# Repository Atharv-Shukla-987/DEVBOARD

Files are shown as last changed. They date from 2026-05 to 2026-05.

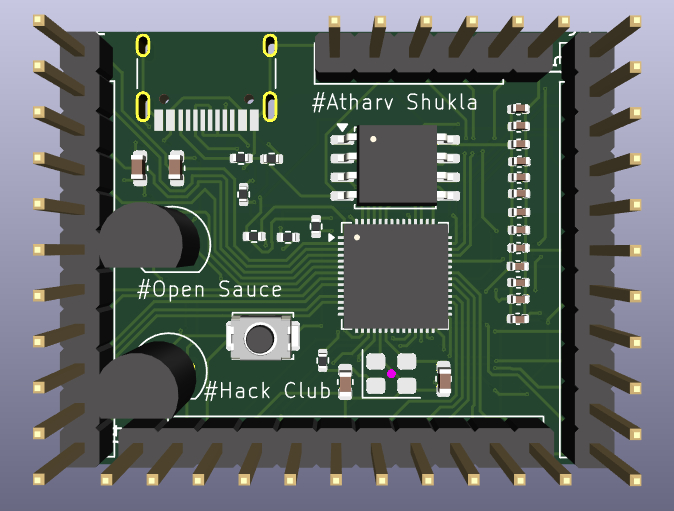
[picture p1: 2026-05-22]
img/Pcb_3d_front.png

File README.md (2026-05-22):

# DEVBOARD
It is devboard made with the help of rp2040 . I try to make it as compact as possible  thus it is a square shaped devboard .It also have many gpio pins. It has following features

##### It has usb C port
##### It has 16MB external QSPI flash
##### It has 1 VBUS , 3v3 and Clock pins 
##### It has 29 gpio pins
##### It has tactile push button for reset

 ## COMPONENTS
#### RP2040
#### MCP1700x-3.3V LDO Regulator (TO-92)
#### W25Q128JVS — 128Mb SPI Flash (SOIC-8)
#### 12 MHz Crystal Oscillator
#### USB-C Receptacle
#### Pin HeaderS
#### Tactile Push Button
#### Capacitors
#### Resistors
 
 ## SCHEMATICS
 I have designed this devboard using kicad. Here are some images

 ### RP2040
RP2040

### USB

Usb

### PINOUT

Pinout

### FLASH STROAGE

Flash Strorage

### CRYSTAL OSCILLATOR

Crystal Oscillator

### DECOUPLING

Decoupling

## FOOTPRINTS
Footprint1

Footprint2

## PCB EDITOR
This is how I traced my devboad.Here its image 

Pcb editor

## 3D VIEW

This how it will look in real life.

### Front

Pcb_3d_front

### Back

Pcb_3d_back

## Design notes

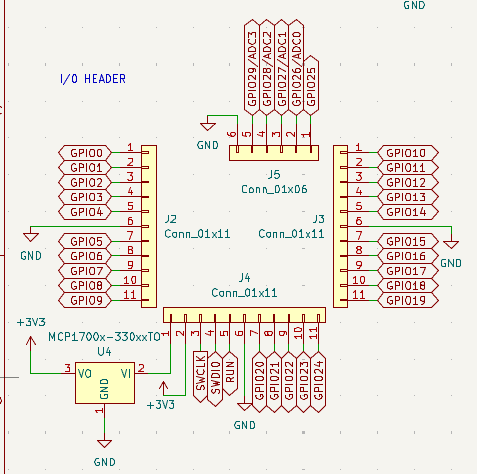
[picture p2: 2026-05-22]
img/Schematics/Pinout.png

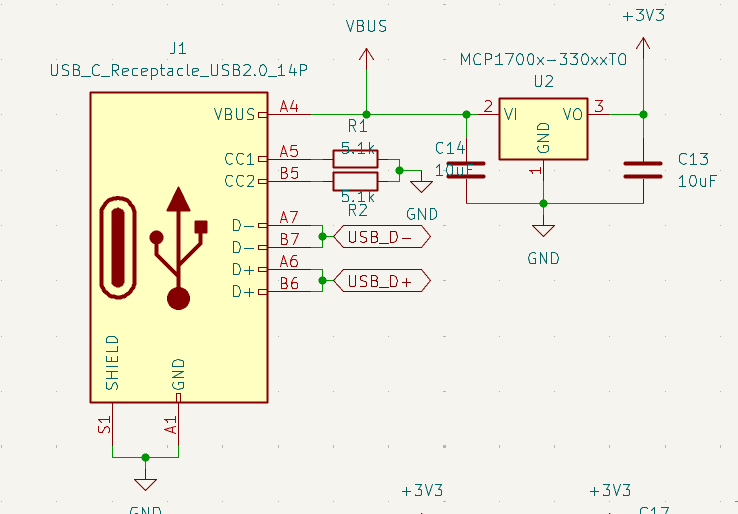
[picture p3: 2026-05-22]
img/Schematics/Usb.png

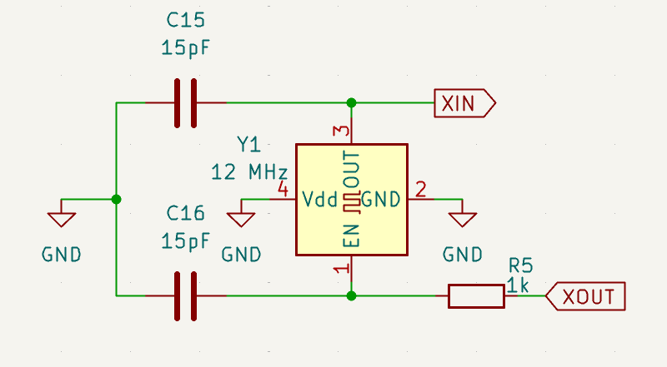
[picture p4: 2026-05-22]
img/Schematics/Crystal Oscillator.png

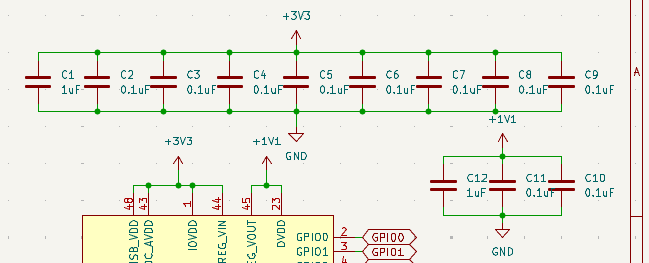
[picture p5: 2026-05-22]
img/Schematics/Decoupling.png

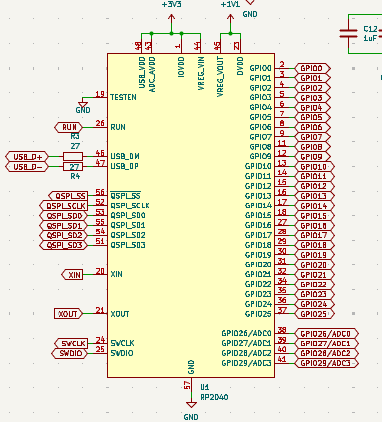
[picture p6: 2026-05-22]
img/Schematics/RP2040.png

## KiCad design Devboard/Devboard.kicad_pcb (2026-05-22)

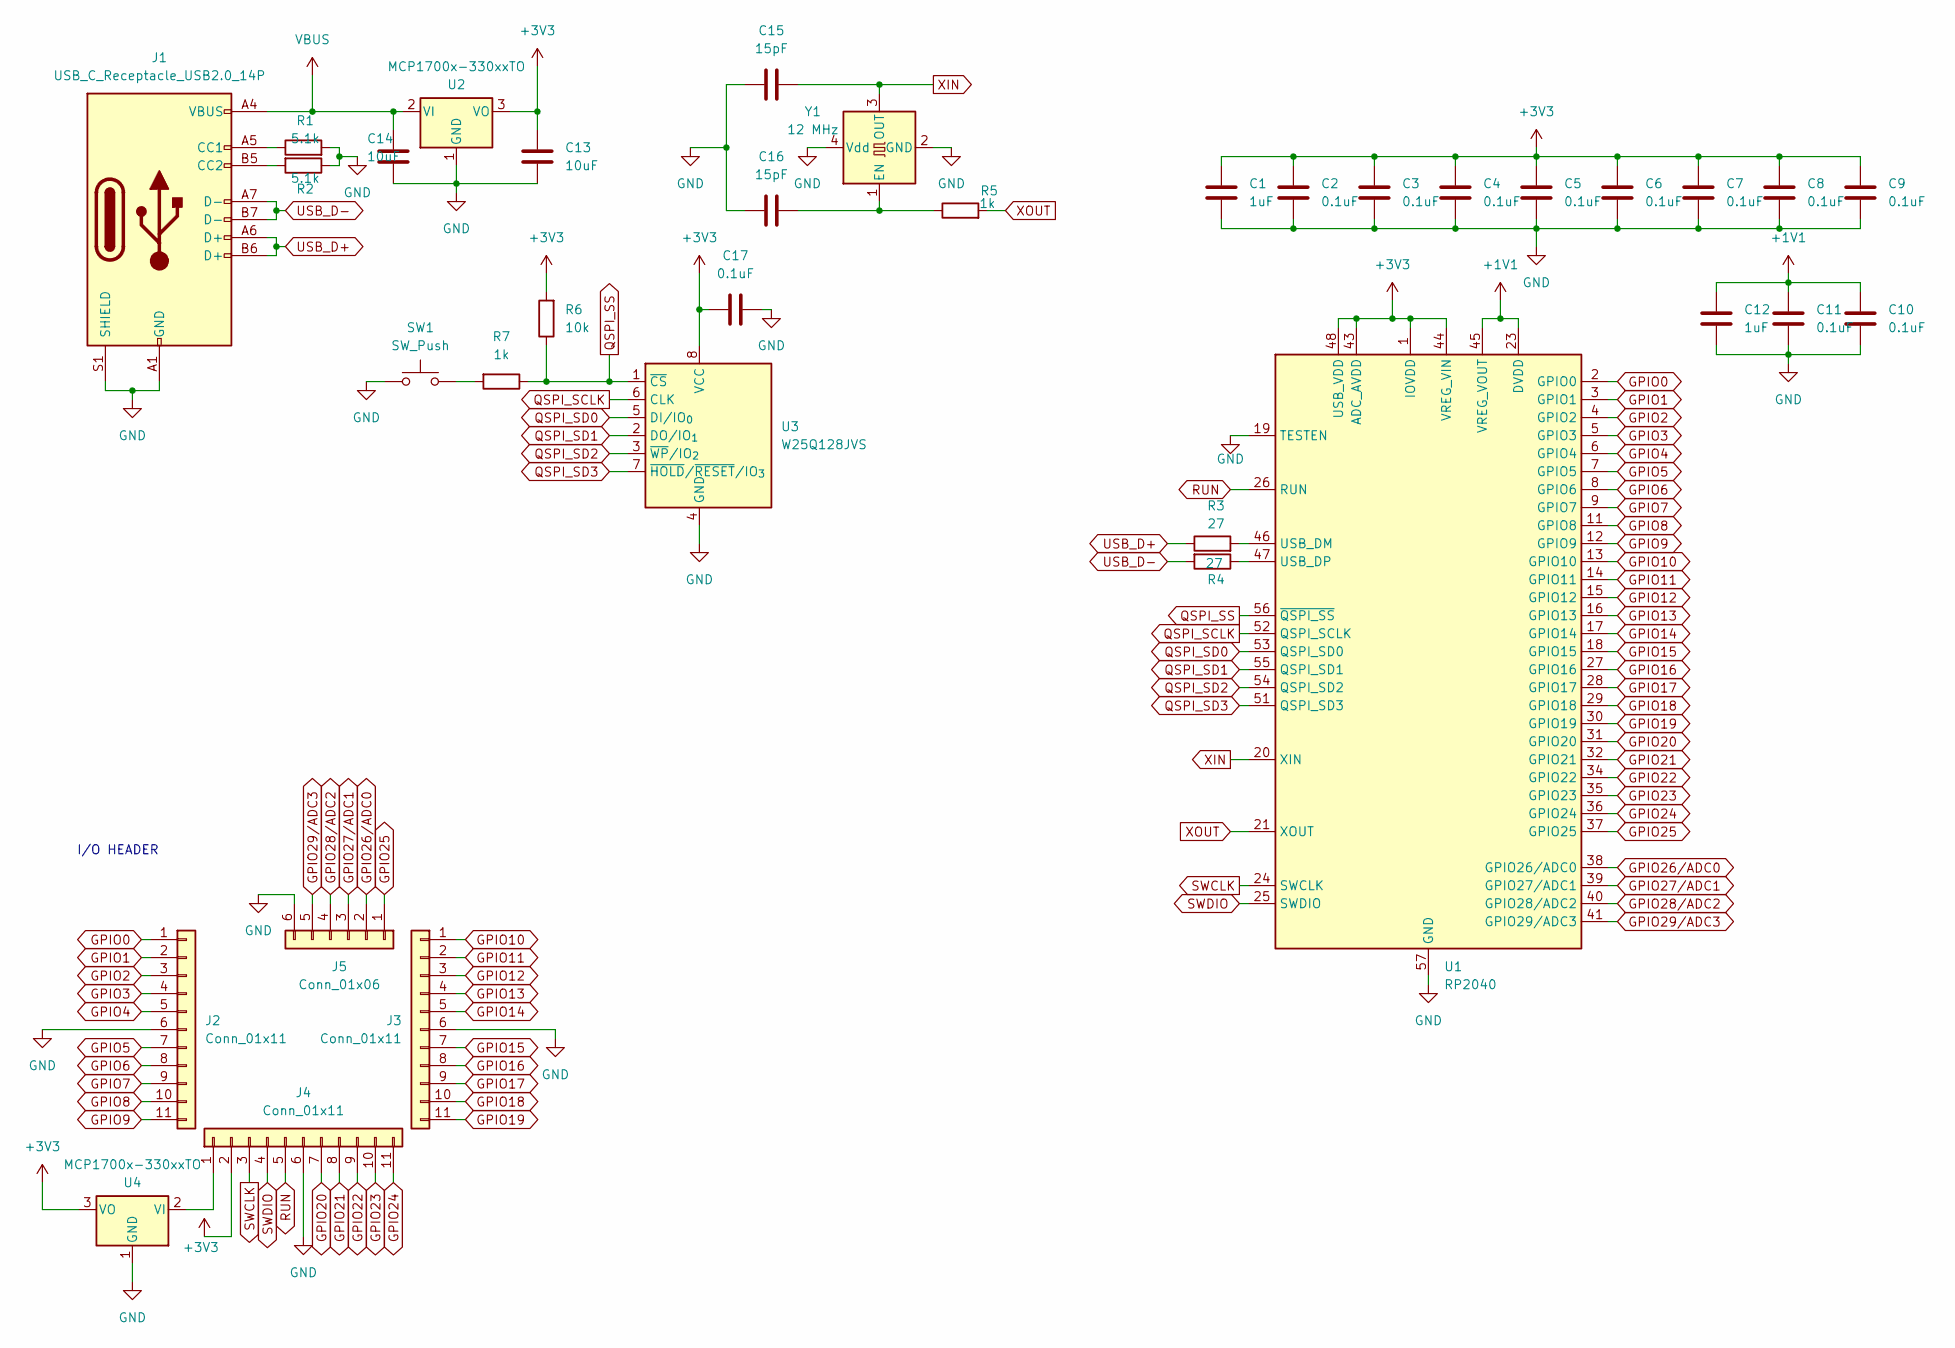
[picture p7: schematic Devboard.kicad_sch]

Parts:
C1, C12: 1uF; C_0402_1005Metric
C2, C3, C4, C5, C6, C7, C8, C9, C10, C11, C17: 0.1uF; C_0402_1005Metric
C13, C14: 10uF; C_0603_1608Metric
C15, C16: 15pF; C_0603_1608Metric
J1: USB_C_Receptacle_USB2.0_14P; USB_C_Receptacle_HRO_TYPE-C-31-M-12
J2, J3, J4: Conn_01x11; PinHeader_1x11_P2.54mm_Vertical
J5: Conn_01x06; PinHeader_1x06_P2.54mm_Vertical
R1, R2: 5.1k; R_0402_1005Metric
R3, R4: 27; R_0402_1005Metric
R5, R7: 1k; R_0402_1005Metric
R6: 10k; R_0402_1005Metric
SW1: SW_Push; SW_Push_SPST_NO_Alps_SKRK
U1: RP2040; QFN-56-1EP_7x7mm_P0.4mm_EP3.2x3.2mm
U2, U4: MCP1700x-330xxTO; TO-92_Inline
U3: W25Q128JVS; SOIC-8_5.3x5.3mm_P1.27mm
Y1: 12 MHz; Oscillator_SMD_Abracon_ASE-4Pin_3.2x2.5mm

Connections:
+1V1: C10.1, C11.1, C12.1, U1.23 (DVDD), U1.45 (VREG_VOUT), U1.50 (DVDD)
+3V3: C1.1, C2.1, C3.1, C4.1, C5.1, C6.1, C7.1, C8.1, C9.1, C13.1, C17.1, J4.2, R6.2, U1.1 (IOVDD), U1.10 (IOVDD), U1.22 (IOVDD), U1.33 (IOVDD), U1.42 (IOVDD), U1.43 (ADC_AVDD), U1.44 (VREG_VIN), U1.48 (USB_VDD), U1.49 (IOVDD), U2.3 (VO), U3.8 (VCC), U4.3 (VO)
GND: C1.2, C2.2, C3.2, C4.2, C5.2, C6.2, C7.2, C8.2, C9.2, C10.2, C11.2, C12.2, C13.2, C14.2, C15.1, C16.1, C17.2, J1.A1 (GND), J1.A12 (GND), J1.B1 (GND), J1.B12 (GND), J1.S1 (SHIELD), J2.6, J3.6, J4.6, J5.6, R1.2, R2.1, SW1.1, U1.19 (TESTEN), U1.57 (GND), U2.1 (GND), U3.4 (GND), U4.1 (GND), Y1.2 (GND), Y1.4 (Vdd)
GPIO0: J2.1, U1.2 (GPIO0)
GPIO1: J2.2, U1.3 (GPIO1)
GPIO2: J2.3, U1.4 (GPIO2)
GPIO3: J2.4, U1.5 (GPIO3)
GPIO4: J2.5, U1.6 (GPIO4)
GPIO5: J2.7, U1.7 (GPIO5)
GPIO6: J2.8, U1.8 (GPIO6)
GPIO7: J2.9, U1.9 (GPIO7)
GPIO8: J2.10, U1.11 (GPIO8)
GPIO9: J2.11, U1.12 (GPIO9)
GPIO10: J3.1, U1.13 (GPIO10)
GPIO11: J3.2, U1.14 (GPIO11)
GPIO12: J3.3, U1.15 (GPIO12)
GPIO13: J3.4, U1.16 (GPIO13)
GPIO14: J3.5, U1.17 (GPIO14)
GPIO15: J3.7, U1.18 (GPIO15)
GPIO16: J3.8, U1.27 (GPIO16)
GPIO17: J3.9, U1.28 (GPIO17)
GPIO18: J3.10, U1.29 (GPIO18)
GPIO19: J3.11, U1.30 (GPIO19)
GPIO20: J4.7, U1.31 (GPIO20)
GPIO21: J4.8, U1.32 (GPIO21)
GPIO22: J4.9, U1.34 (GPIO22)
GPIO23: J4.10, U1.35 (GPIO23)
GPIO24: J4.11, U1.36 (GPIO24)
GPIO25: J5.1, U1.37 (GPIO25)
GPIO26/ADC0: J5.2, U1.38 (GPIO26/ADC0)
GPIO27/ADC1: J5.3, U1.39 (GPIO27/ADC1)
GPIO28/ADC2: J5.4, U1.40 (GPIO28/ADC2)
GPIO29/ADC3: J5.5, U1.41 (GPIO29/ADC3)
unnamed: J1.A5 (CC1), R1.1
unnamed: J1.B5 (CC2), R2.2
unnamed: J4.1, U4.2 (VI)
unnamed: R7.2, SW1.2
unnamed: R3.2, U1.46 (USB_DM)
unnamed: R4.1, U1.47 (USB_DP)
unnamed: C16.2, R5.1, Y1.1 (EN)
QSPI_SCLK: U1.52 (QSPI_SCLK), U3.6 (CLK)
QSPI_SD0: U1.53 (QSPI_SD0), U3.5 (DI/IO_{0})
QSPI_SD1: U1.55 (QSPI_SD1), U3.2 (DO/IO_{1})
QSPI_SD2: U1.54 (QSPI_SD2), U3.3 (~WP/IO_{2})
QSPI_SD3: U1.51 (QSPI_SD3), U3.7 (~HOLD/~RESET/IO_{3})
QSPI_SS: R6.1, R7.1, U1.56 (~QSPI_SS), U3.1 (~CS)
RUN: J4.5, U1.26 (RUN)
SWCLK: J4.3, U1.24 (SWCLK)
SWDIO: J4.4, U1.25 (SWDIO)
USB_D+: J1.A6 (D+), J1.B6 (D+), R3.1
USB_D-: J1.A7 (D-), J1.B7 (D-), R4.2
VBUS: C14.1, J1.A4 (VBUS), J1.A9 (VBUS), J1.B4 (VBUS), J1.B9 (VBUS), U2.2 (VI)
XIN: C15.2, U1.20 (XIN), Y1.3 (OUT)
XOUT: R5.2, U1.21 (XOUT)

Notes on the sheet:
I/O HEADER

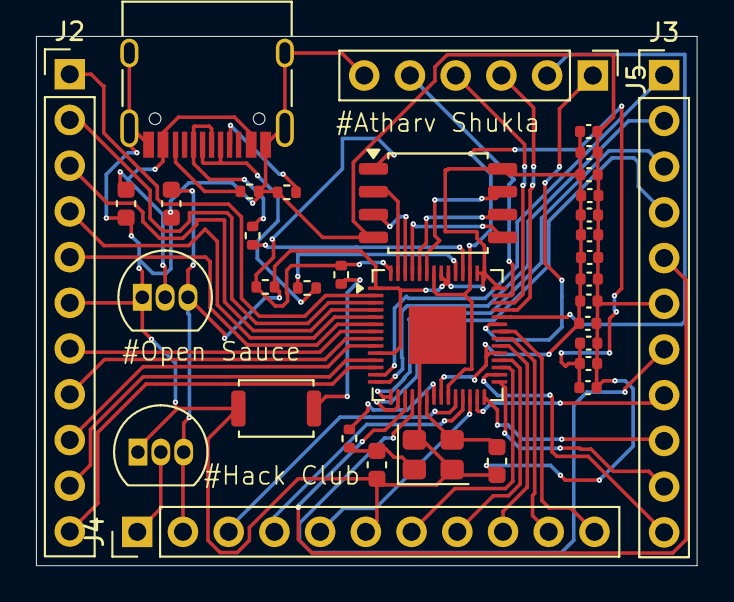
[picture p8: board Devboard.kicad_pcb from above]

Board: 2 copper layers, 36.7 x 29.4 mm, 35 parts (0 on the bottom side), 54 nets.
